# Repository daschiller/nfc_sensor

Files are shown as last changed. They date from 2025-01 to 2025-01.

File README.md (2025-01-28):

# Introduction

Source code and PCB design files for an NFC-enabled sweat sensor.  Published as
part of ["Stretchable and biodegradable batteries with high energy and power
density"](https://doi.org/10.1002/adma.202204457).

# Hardware

The board has been designed in KiCad. You can use it to generate your own Gerbers.

Here's a shortened BOM:

* MCU: ATtiny85V
* NFC tag: ST25DV64K

# Software

Two build systems can be used:

* PlatformIO
* Traditional Makefile using standard toolchain (avr-gcc, avrdude)

I recommend an SOIC-8 clip for flashing.

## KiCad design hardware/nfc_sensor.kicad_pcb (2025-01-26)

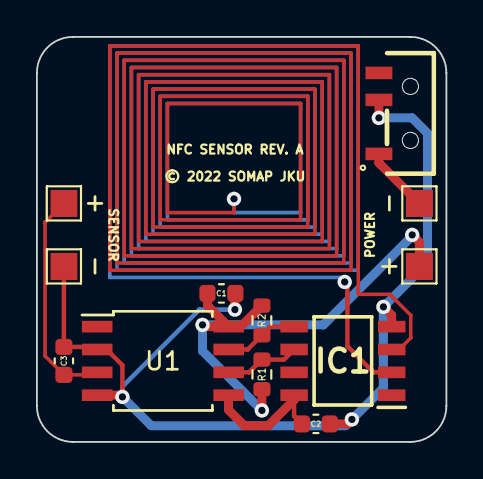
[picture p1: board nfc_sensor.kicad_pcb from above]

Board: 2 copper layers, 22.8 x 22.5 mm, 12 parts (0 on the bottom side), 6 nets.

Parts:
+: TestPoint_Pad_1.5x1.5mm
+#2: TestPoint_Pad_1.5x1.5mm
-: TestPoint_Pad_1.5x1.5mm
-#2: TestPoint_Pad_1.5x1.5mm
C1: 10u; C_0603_1608Metric
C2: 100n; C_0603_1608Metric
C3: 47n; C_0603_1608Metric
IC1: ST25DV64K-IER6S3; SOIC127P600X175-8N
R1, R2: 4.7k; R_0603_1608Metric
SW1: SSSS810701
U1: ATtiny85V-10SU; SOIC-8W_5.3x5.3mm_P1.27mm

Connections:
+BATT: +.1, C1.1, R1.1, R2.1, U1.8 (VCC)
ADC+: +#2.1, C3.1, U1.3 (XTAL2/PB4)
GND: -.1, -#2.1, C1.2, C2.2, C3.2, IC1.4 (VSS), SW1.1, SW1.2, U1.2 (XTAL1/PB3), U1.4 (GND)
PB1: C2.1, IC1.8 (VCC), U1.5 (AREF/PB0)
SCL: IC1.6 (SCL), R1.2, U1.6 (PB1)
SDA: IC1.5 (SDA), R2.2, U1.7 (PB2)

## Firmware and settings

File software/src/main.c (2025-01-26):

// SPDX-License-Identifier: GPL-3.0-only

/*
 *  Copyright (c) 2022 David Schiller <david.schiller@jku.at>
 */

#include "i2cmaster.h"
#include <avr/interrupt.h>
#include <avr/io.h>
#include <avr/power.h>
#include <avr/sleep.h>
#include <util/atomic.h>
#include <util/delay.h>

// #define STATUS_LED
// #define LED PB1

#define TAG PB1
#define ARRAY_SIZE 1                          // 256 bytes
#define TAG_SIZE 512                          // 512 bytes
#define PACKET_NO TAG_SIZE / (ARRAY_SIZE * 2) // number of packets on tag
#define DELAY 100                             // milliseconds
#define ST25DV_DATA 0xA6
#define SKIP_INTERVAL 5

// globals
uint16_t adc_offset;
uint16_t adc_values[ARRAY_SIZE];

#ifdef STATUS_LED
void init_led(void) {
    PORTB &= ~_BV(LED);
    DDRB |= _BV(LED);
}

void error_led(void) { PORTB |= _BV(LED); }

void toggle_led(void) {
    PORTB |= _BV(LED);
    _delay_ms(5);
    PORTB &= ~_BV(LED);
}
#endif

uint16_t read_adc(void) {
    // settling time for internal voltage reference
    _delay_us(100);

    // 16x oversampling (2 additional bits of resolution)
    uint16_t avg = 0;
    for (int i = 0; i < 16; i++) {
        ADCSRA |= _BV(ADSC);
        loop_until_bit_is_clear(ADCSRA, ADSC);
        avg += ADCW;
    }

    // return average
    // divide unsigned value by power of 2 -> right shift
    return avg / 16 - adc_offset;

    // return 12 bit oversampled measurement
    // return (avg >> 2) - adc_offset;
}

void init_adc(void) {
    // enable internal 1.1V reference
    ADMUX = _BV(REFS1);
    // inital settling time after selecting reference
    _delay_ms(1);
    // disable digital input buffers on ADC2 and ADC3
    DIDR0 = _BV(ADC2D) | _BV(ADC3D);
    // divide ADC clock by 16
    ADCSRA = _BV(ADPS2);
    // enable ADC
    ADCSRA |= _BV(ADEN);

    // offset measurement (ADC2 for both inputs, 20x gain)
    // ADMUX |= _BV(MUX2) | _BV(MUX0);
    ADMUX |= _BV(MUX2);
    adc_offset = read_adc();

    // set ADC2 as positive input, ADC3 as negative input and gain to 20x
    // ADMUX |= _BV(MUX2) | _BV(MUX1) | _BV(MUX0);
    ADMUX |= _BV(MUX2) | _BV(MUX1);
}

void write_nfc(uint16_t address, uint16_t *buffer, int size) {
    // power on tag
    PORTB |= _BV(TAG);
    // wait for boot-up
    _delay_ms(1);

    // temporarily switch clock to 2 MHz
    clock_prescale_set(clock_div_4);
    i2c_start_wait(ST25DV_DATA);
    // write address
    i2c_write(address >> 8);
    i2c_write(address);
    // write data
    for (int i = 0; i < size; i++) {
        i2c_write(buffer[i] >> 8);
        i2c_write(buffer[i]);
    }
    i2c_stop();
    clock_prescale_set(clock_div_64);
    // poll for EEPROM write completion
    i2c_start_wait(ST25DV_DATA);
    i2c_stop();

    _delay_ms(1);
    // power off tag
    PORTB &= ~_BV(TAG);
}

#if F_CPU <= 31250UL
void init_timer(void) {
    // set timer to CTC mode
    TCCR0A = _BV(WGM01);
    // set counter to overflow after one second
    OCR0A = F_CPU / 256 - 1;
    // enable timer and divide F_CPU by 256
    TCCR0B = _BV(CS02);
    // enable timer compare interrupt in mask
    TIMSK |= _BV(OCIE0A);
    sei();
}
#endif

void init_wdt(void) {
    // enable watchdog interrupts for (roughly) every one second
    // WDTCR = _BV(WDIE) | _BV(WDP2) | _BV(WDP1);

    WDTCR = _BV(WDIE) | _BV(WDP3) | _BV(WDP0);
    sei();
}

void sleep(void) {
    // disable ADC
    ADCSRA &= ~_BV(ADEN);
    sleep_mode();
    // enable ADC
    ADCSRA |= _BV(ADEN);
}

EMPTY_INTERRUPT(TIM0_COMPA_vect)
EMPTY_INTERRUPT(WDT_vect)

// do not push locally used registers
// we don't use the stack at all (except for return addresses)
__attribute__((OS_main)) int main(void) {
    uint8_t skip_interval = SKIP_INTERVAL;

    // divide clock by 64 (125 kHz)
    clock_prescale_set(clock_div_64);
    // turn off analog comparator
    ACSR |= _BV(ACD);
    power_usi_disable();
    power_timer0_disable();
    power_timer1_disable();

    // enable pull-ups to prevent floating inputs
    // PORTB = 0xFF;

    // initialize tag VCC pin
    PORTB &= ~_BV(TAG);
    DDRB |= _BV(TAG);

    uint16_t address = 0x0000;

#ifdef STATUS_LED
    init_led();
#endif
    i2c_init();
    init_adc();
    _delay_ms(1000);

    // more precise (exactly one second)
    // set_sleep_mode(SLEEP_MODE_IDLE);
    // init_timer();

    // less precise, but allows power-down sleep
    set_sleep_mode(SLEEP_MODE_PWR_DOWN);
    init_wdt();

    for (int i = 0; i < PACKET_NO; i++) {
        for (int j = 0; j < ARRAY_SIZE; j++) {
            sleep();
#ifdef STATUS_LED
            toggle_led();
#endif
            while (skip_interval--) {
                sleep();
            }
            skip_interval = SKIP_INTERVAL;
            adc_values[j] = read_adc();
        }
        // ensure that no interrupts are fired when we write to the tag
        ATOMIC_BLOCK(ATOMIC_RESTORESTATE) {
            write_nfc(address, adc_values, ARRAY_SIZE);
        }
        address += ARRAY_SIZE * 2;
    }
    cli();
    _delay_ms(1000);
#ifdef STATUS_LED
    error_led();
#endif
    // disable ADC
    // ADCSRA &= ~_BV(ADEN);
    while (1) {
        ADCSRA |= _BV(ADSC);
        loop_until_bit_is_clear(ADCSRA, ADSC);
    };
}

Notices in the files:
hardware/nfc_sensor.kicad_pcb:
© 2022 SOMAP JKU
